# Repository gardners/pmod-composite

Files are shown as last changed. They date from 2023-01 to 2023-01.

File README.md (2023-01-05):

PMOD Composite Output Board
===========================

Designed for use with FPGA boards used as DIY MEGA65 machines.

The DAC uses 4 FPGA pins per channel. It is designed for the
FPGA to massively over-sample the outputs to obtain 4 bits of
precision per FPGA line. Thus 16 bit precision per line should
be possible.  Most of the components on the board are the filter
to smooth out the switching noise from driving the pins at 540MHz
(270MHz DDR) to produce a nice clean 13.5MHz clocked composite
signal.  Should work fine as an audio DAC, too.

Design is all hole-through for easy assembly at home.

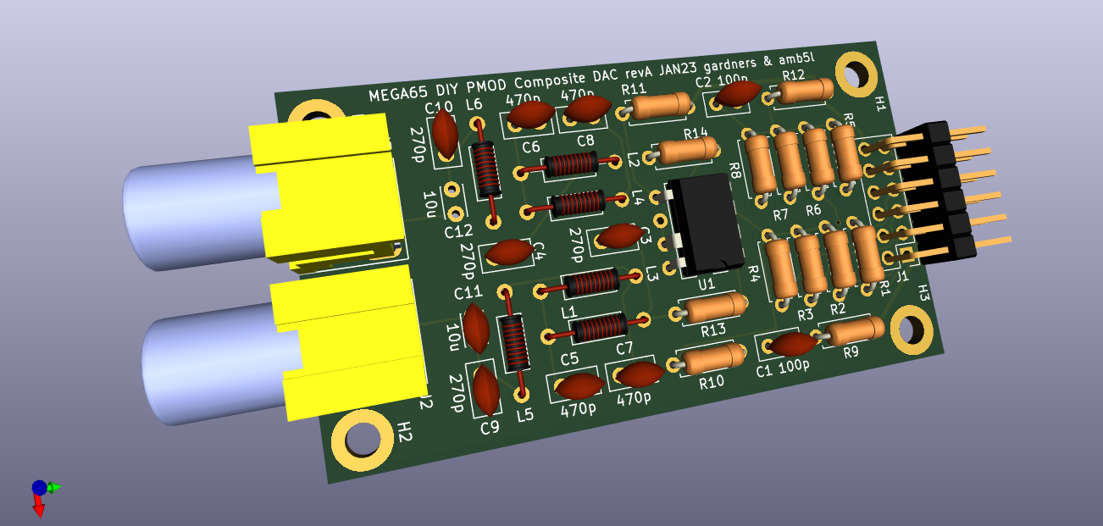
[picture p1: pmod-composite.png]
3d render of PCB


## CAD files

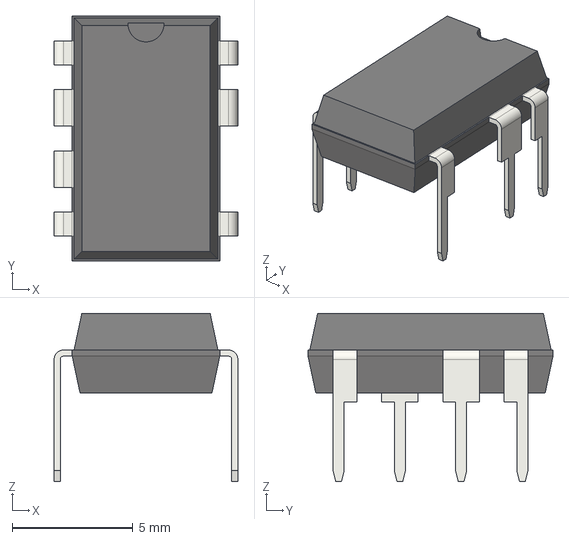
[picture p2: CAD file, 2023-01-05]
pmod-composite/DIP-8-N6_W7.62mm.step
7.62 x 10.2 x 6.98 mm

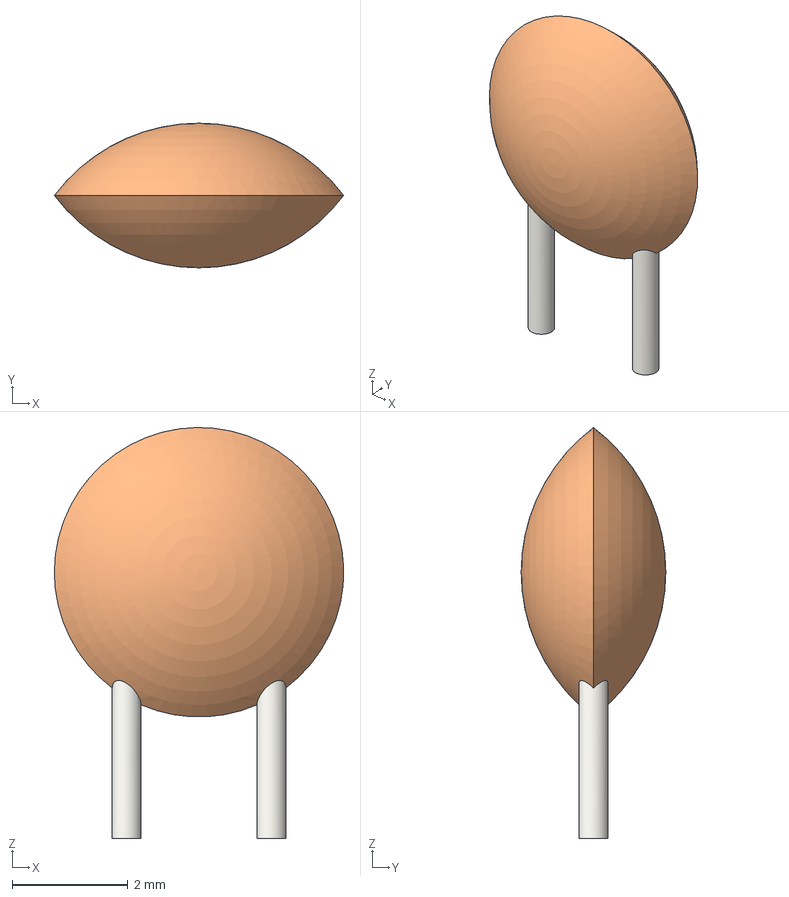
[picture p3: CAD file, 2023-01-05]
pmod-composite/C_Disc_D5.0mm_W2.5mm_P2.50mm.step
5.00 x 2.50 x 7.10 mm

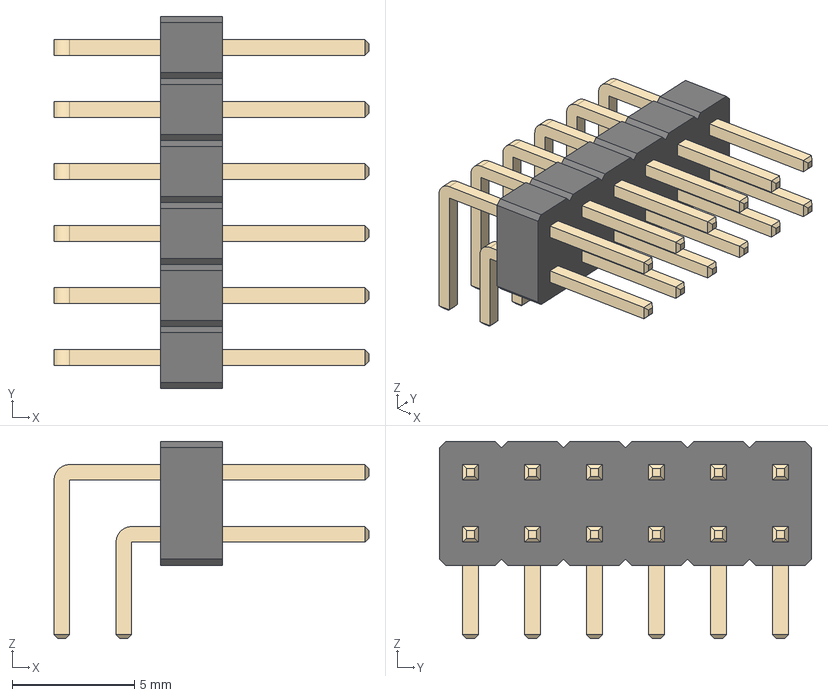
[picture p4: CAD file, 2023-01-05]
pmod-composite/PinHeader_2x06_P2.54mm_Horizontal.step
12.9 x 15.2 x 8.08 mm

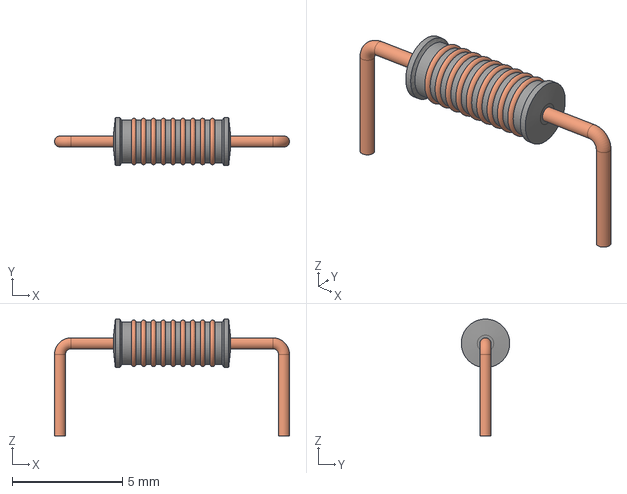
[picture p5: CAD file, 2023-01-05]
pmod-composite/L_Axial_L5.3mm_D2.2mm_P10.16mm_Horizontal_Vishay_IM-1.step
10.7 x 2.20 x 5.30 mm

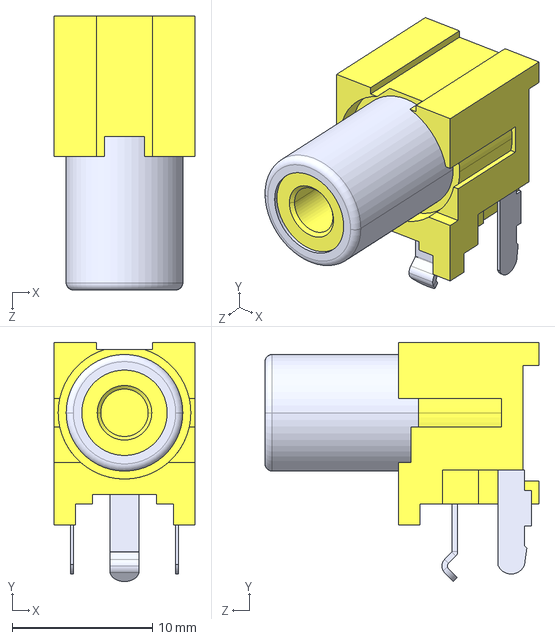
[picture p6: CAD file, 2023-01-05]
pmod-composite/PJRAN1X1U04X.step
10.0 x 17.0 x 19.5 mm

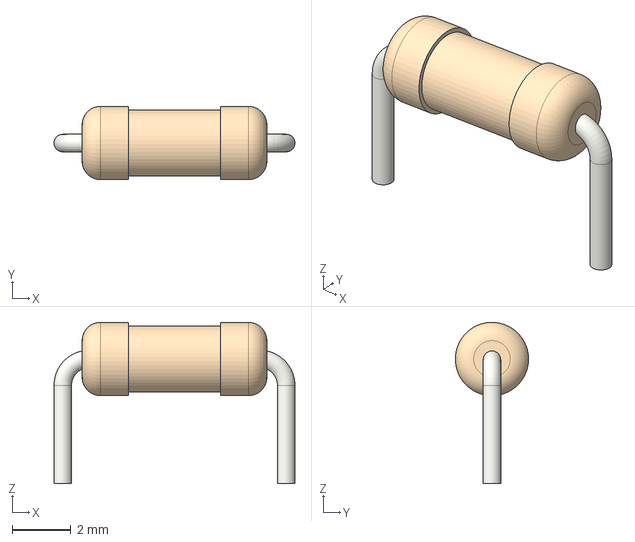
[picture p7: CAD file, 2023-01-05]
pmod-composite/R_Axial_DIN0207_L6.3mm_D2.5mm_P7.62mm_Horizontal.step
8.22 x 2.50 x 5.50 mm

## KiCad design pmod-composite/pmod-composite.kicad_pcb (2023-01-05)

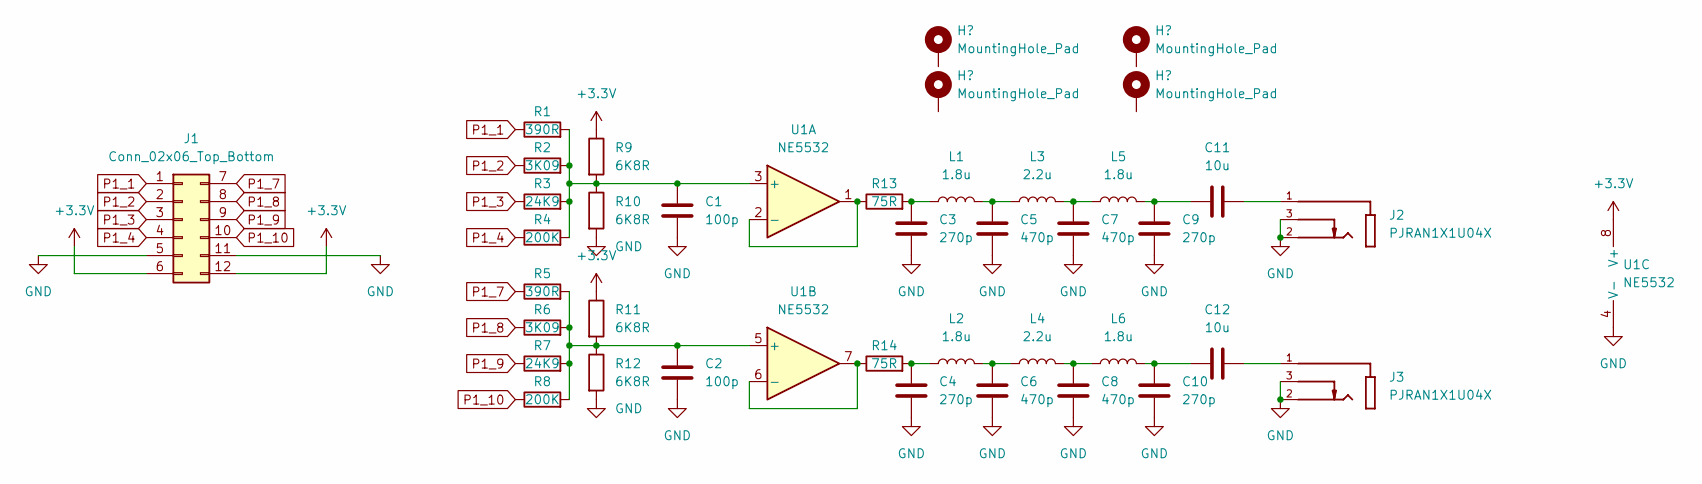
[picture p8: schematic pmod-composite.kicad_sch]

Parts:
C1, C2: 100p; C_Disc_D5.0mm_W2.5mm_P2.50mm
C3, C4, C9, C10: 270p; C_Disc_D5.0mm_W2.5mm_P2.50mm; DigikeyPart FG28C0G1H271JNT06
C5, C6, C7, C8: 470p; C_Disc_D5.0mm_W2.5mm_P2.50mm
C11, C12: 10u; C_Disc_D3.0mm_W2.0mm_P2.50mm; DigikeyPart FG18X5R1E106MRT06
J1: Conn_02x06_Top_Bottom; PMOD
J2, J3: PJRAN1X1U04X; SWITCHCRAFT_PJRAN1X1U04X; PARTREV A; DigikeyPart PJRAN1X1U04X-ND
L1, L2, L5, L6: 1.8u; L_Axial_L5.3mm_D2.2mm_P10.16mm_Horizontal_Vishay_IM-1; DigikeyPart 78F1R8K-RC
L3, L4: 2.2u; L_Axial_L5.3mm_D2.2mm_P10.16mm_Horizontal_Vishay_IM-1; DigikeyPart 78F2R2K-RC
R1, R5: 390R; R_Axial_DIN0207_L6.3mm_D2.5mm_P7.62mm_Horizontal
R2, R6: 3K09; R_Axial_DIN0207_L6.3mm_D2.5mm_P7.62mm_Horizontal
R3, R7: 24K9; R_Axial_DIN0207_L6.3mm_D2.5mm_P7.62mm_Horizontal
R4, R8: 200K; R_Axial_DIN0207_L6.3mm_D2.5mm_P7.62mm_Horizontal
R9, R10, R11, R12: 6K8R; R_Axial_DIN0207_L6.3mm_D2.5mm_P7.62mm_Horizontal
R13, R14: 75R; R_Axial_DIN0207_L6.3mm_D2.5mm_P7.62mm_Horizontal
U1: NE5532; DIP-8_W7.62mm

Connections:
+3V3: J1.6, J1.12, R9.1, R11.1, U1.8 (V+)
GND: C1.2, C2.2, C3.2, C4.2, C5.2, C6.2, C7.2, C8.2, C9.2, C10.2, J1.5, J1.11, J2.2, J2.3, J3.2, J3.3, R10.2, R12.2, U1.4 (V-)
unnamed: C1.1, R1.2, R2.2, R3.2, R4.2, R9.2, R10.1, U1.3 (+)
unnamed: C2.1, R5.2, R6.2, R7.2, R8.2, R11.2, R12.1, U1.5 (+)
unnamed: C3.1, L1.1, R13.2
unnamed: C4.1, L2.1, R14.2
unnamed: C5.1, L1.2, L3.1
unnamed: C6.1, L2.2, L4.1
unnamed: C7.1, L3.2, L5.1
unnamed: C8.1, L4.2, L6.1
unnamed: C10.1, C12.1, L6.2
unnamed: C9.1, C11.1, L5.2
unnamed: C11.2, J2.1
unnamed: C12.2, J3.1
unnamed: R13.1, U1.1, U1.2 (-)
unnamed: R14.1, U1.6 (-), U1.7
P1_1: J1.1, R1.1
P1_2: J1.2, R2.1
P1_3: J1.3, R3.1
P1_4: J1.4, R4.1
P1_7: J1.7, R5.1
P1_8: J1.8, R6.1
P1_9: J1.9, R7.1
P1_10: J1.10, R8.1

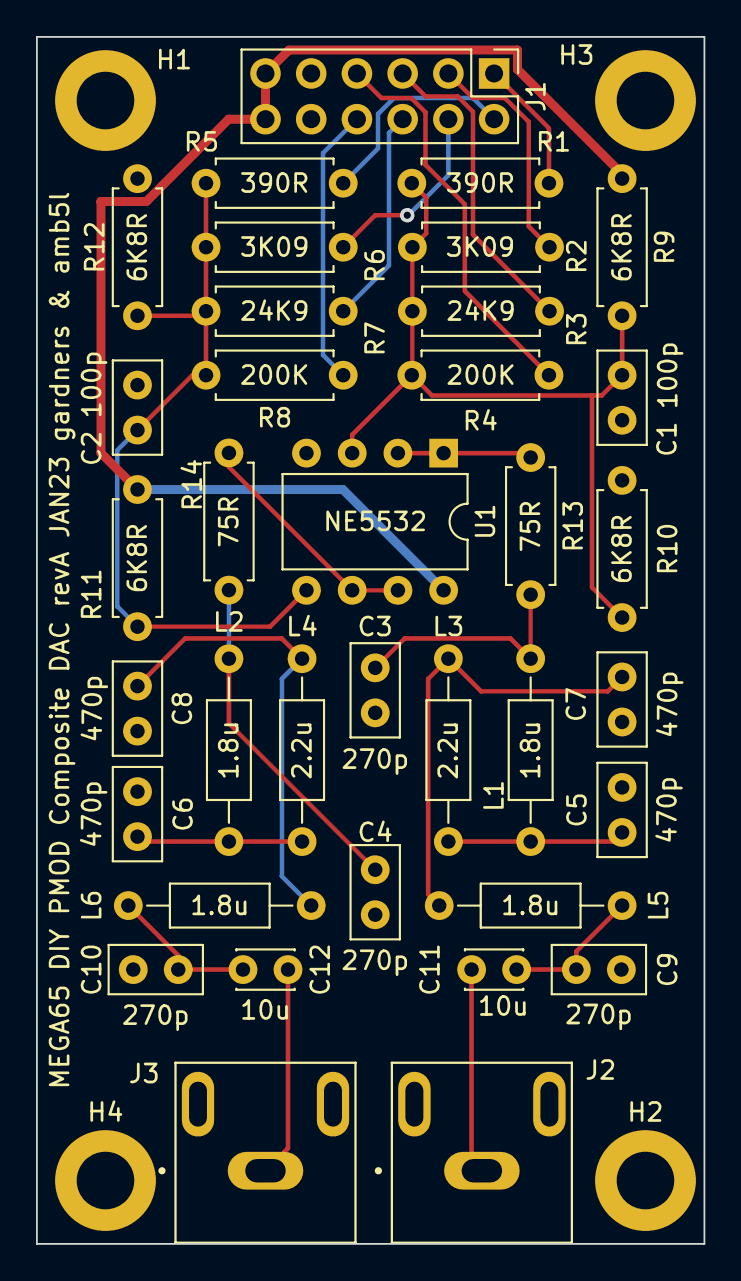
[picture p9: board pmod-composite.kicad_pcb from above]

Board: 2 copper layers, 37.1 x 67.1 mm, 40 parts (0 on the bottom side), 24 nets.

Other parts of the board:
H1, H2, H3, H4: MountingHole_Pad; MountingHole_3.2mm_M3_DIN965_Pad

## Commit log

2023-01-04 begin implementing PMOD composite adaptor
    [pmod-composite.kicad_pcb, pmod-composite.kicad_sch]
2023-01-04 add many footprints
    [pmod-composite.kicad_sch]
2023-01-04 add connector footprint
    [pmod-composite.kicad_sch]
2023-01-04 work on PCB layout
    [pmod-composite.kicad_pcb, pmod-composite.kicad_sch]
2023-01-05 route board
    [pmod-composite.kicad_pcb, pmod-composite.kicad_sch]
2023-01-05 begin adding 3D models for components
    [PJRAN1X1U04X.step, R_Axial_DIN0207_L6.3mm_D2.5mm_P7.62mm_Horizontal.step, pmod-composite.kicad_pcb]
2023-01-05 finish adding 3d models
    [C_Disc_D5.0mm_W2.5mm_P2.50mm.step, DIP-8-N6_W7.62mm.step, L_Axial_L5.3mm_D2.2mm_P10.16mm_Horizontal_Vishay_IM-1.step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]
2023-01-05 relocate README.
    [pmod-composite.kicad_pcb, pmod-composite.kicad_sch]

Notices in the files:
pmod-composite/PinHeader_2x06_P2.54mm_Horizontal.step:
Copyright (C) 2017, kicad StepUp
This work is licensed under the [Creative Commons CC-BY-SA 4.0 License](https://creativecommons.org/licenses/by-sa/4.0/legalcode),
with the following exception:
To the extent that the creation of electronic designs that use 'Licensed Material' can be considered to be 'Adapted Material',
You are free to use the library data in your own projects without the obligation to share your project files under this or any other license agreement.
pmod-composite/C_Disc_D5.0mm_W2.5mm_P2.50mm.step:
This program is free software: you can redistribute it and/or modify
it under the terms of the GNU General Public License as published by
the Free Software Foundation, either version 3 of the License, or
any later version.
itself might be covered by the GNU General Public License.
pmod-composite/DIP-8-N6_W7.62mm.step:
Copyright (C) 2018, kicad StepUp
